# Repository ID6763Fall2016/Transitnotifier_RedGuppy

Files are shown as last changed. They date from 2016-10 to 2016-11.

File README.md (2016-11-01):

# Transitnotifier_RedGuppy
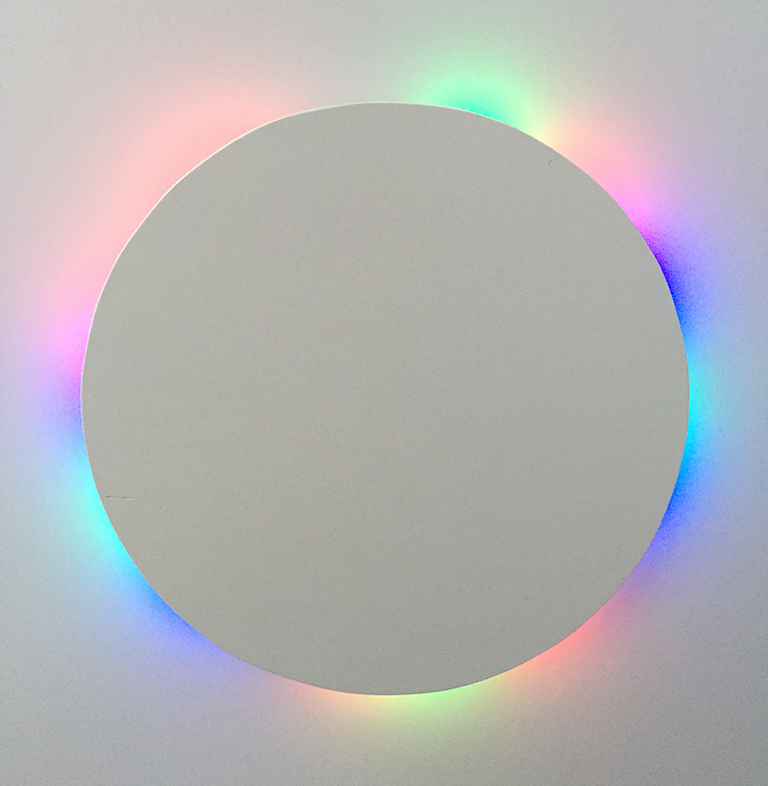
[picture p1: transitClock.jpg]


This is the transit notifier project called Buzz Clock.
You will need the following hardware and software to build the Buzz Clock: 

Hardware:
<ul>
<li>ESP8266 x 1 (adafruit Huzzah breakout for the PCB we used)</li> 
<li>NeoPixel strip x 1 (60 neoPixels.  You can use less but you'll need to modify the code heavily)</li>
<li>Battery x 1 (or a USB 5 volt power supply with power and ground connections</li>
<li>Resistor x 2 (10k and 470R)</li>
<li>Capacitor x 1 (1000U 16v or 24v) </li>
<li>Push button x 1</li>
</ul>

Software:
<ul>
<li>Adafruit NeoPixel library</li>
<li>WiFi Client Secure library</li>
<li>TinyXML library</li>
</ul>

The working code resides in the NextBusGT folder. After connecting the hardwares together and connecting ESP8266 to your laptop, you need to modify the code with your wifi SSID and Password then upload the code to the ESP8266 and it will start retrieve the data from the xml provided by http://gtbuses.herokuapp.com.

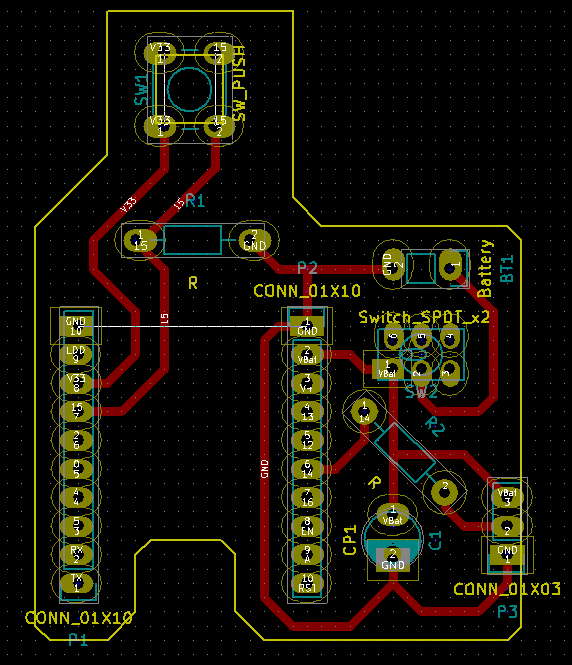
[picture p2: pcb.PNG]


If you wish to make your own PCB instead of using a breadboard for the setup you can start with our CAD files in the WiFiNeoClock director.  We used KiCad to create the board.  Additional information on working with kiCad can be found at..
http://kicad-pcb.org/

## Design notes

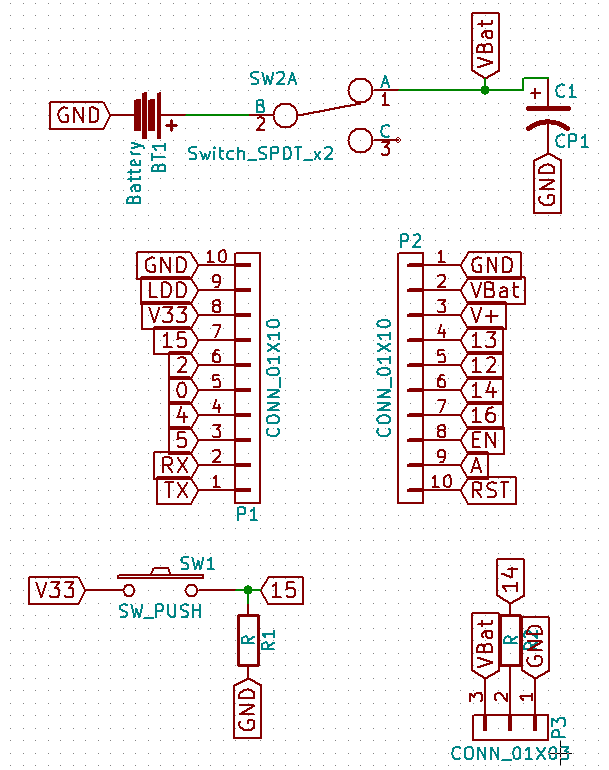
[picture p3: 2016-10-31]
schematic.PNG

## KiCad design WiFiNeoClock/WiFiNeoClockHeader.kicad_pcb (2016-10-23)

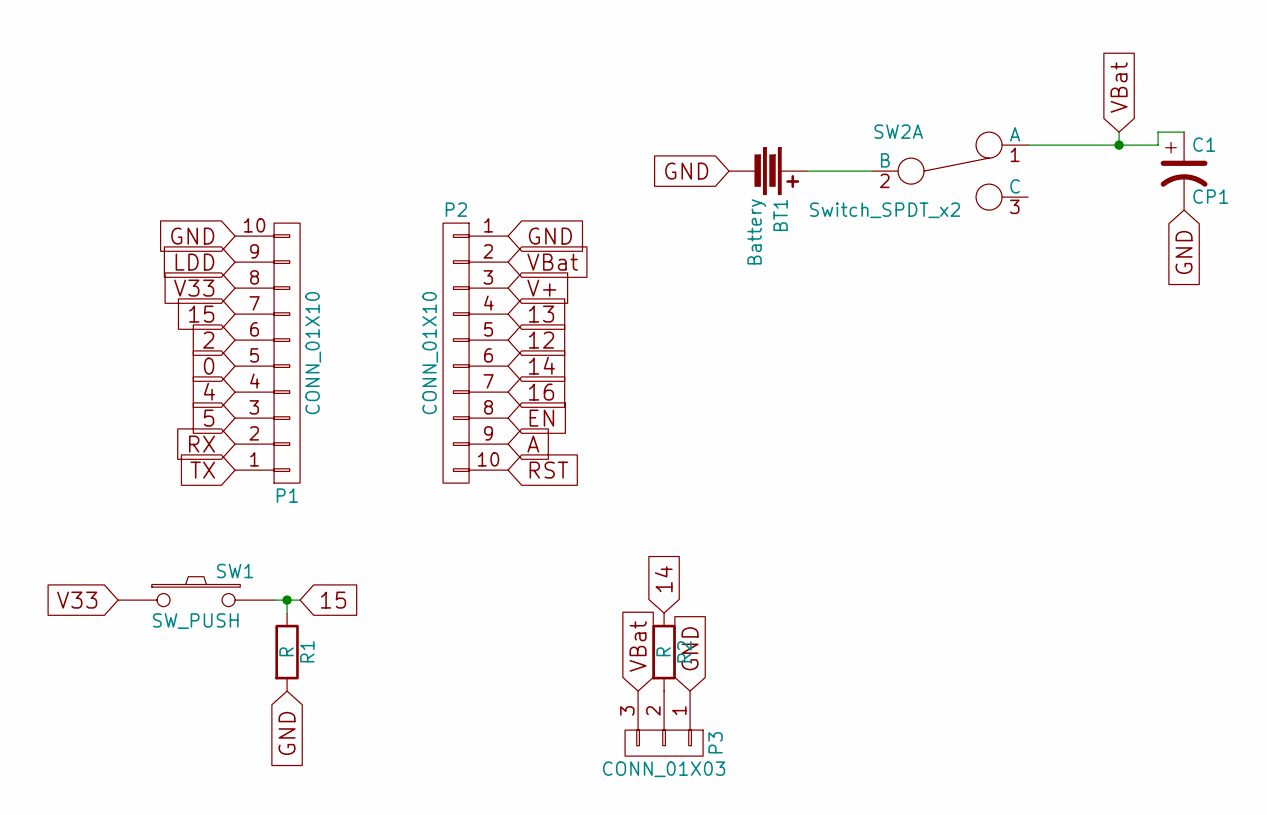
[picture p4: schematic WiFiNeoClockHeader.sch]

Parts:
BT1: Battery; Pin_Header_Straight_1x02
C1: CP1; C_Radial_D5_L11_P2.5
P1, P2: CONN_01X10; Pin_Header_Straight_1x10
P3: CONN_01X03; Pin_Header_Straight_1x03
R1, R2: R; Resistor_Horizontal_RM10mm
SW1: SW_PUSH; SW_PUSH_6mm
SW2: Switch_SPDT_x2; SW_NKK_G1xJP

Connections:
0: P1.5
2: P1.6
4: P1.4
5: P1.3
12: P2.5
13: P2.4
14: P2.6, R2.1
15: P1.7, R1.1, SW1.2
16: P2.7
A: P2.9
EN: P2.8
GND: BT1.2, C1.2, P1.10, P2.1, P3.1, R1.2
LDD: P1.9
unnamed: BT1.1, SW2.2 (B)
unnamed: P3.2, R2.2
RST: P2.10
RX: P1.2
TX: P1.1
V33: P1.8, SW1.1
V+: P2.3
VBat: C1.1, P2.2, P3.3, SW2.1 (A)

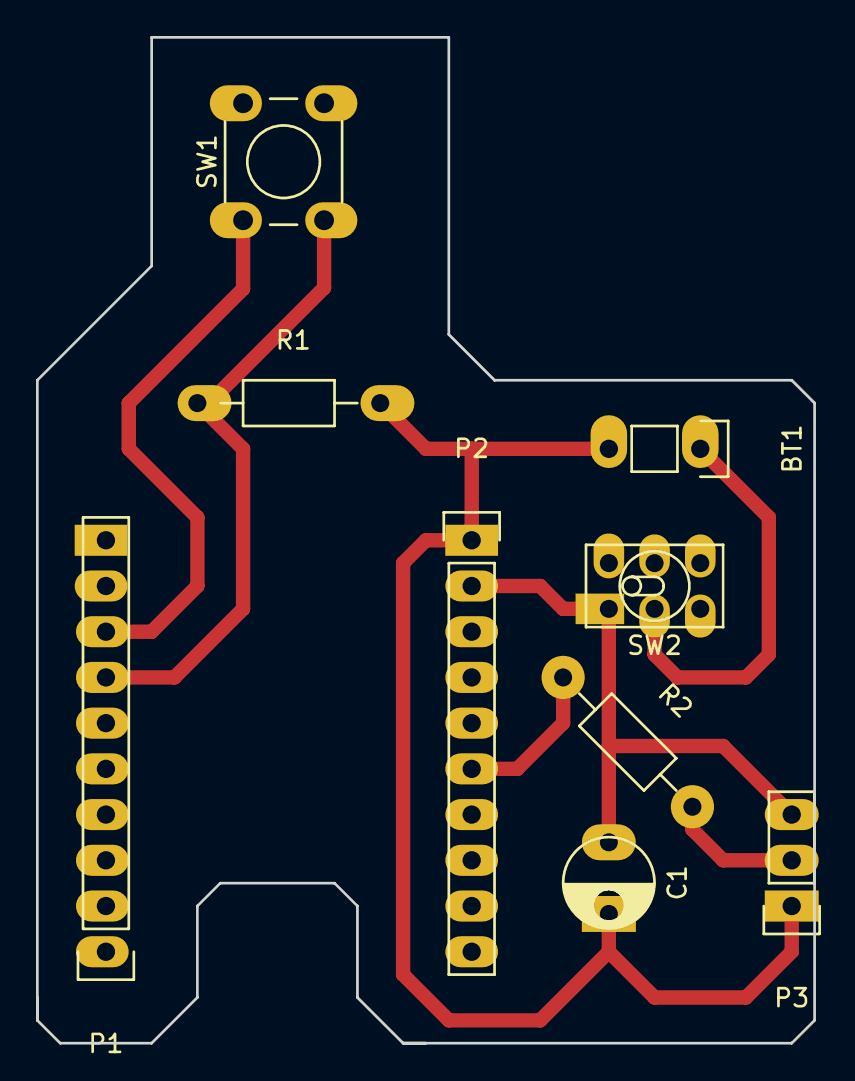
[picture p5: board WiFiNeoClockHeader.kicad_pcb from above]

Board: 2 copper layers, 43.2 x 55.9 mm, 9 parts (0 on the bottom side), 7 nets.

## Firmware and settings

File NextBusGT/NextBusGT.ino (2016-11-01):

/*
 *  HTTP over TLS (HTTPS) example sketch
 *  This program uses the Nextbus api at gtbuses.herokuapp.com to map the bus arrival times
 *  to a clock.  The idea is to present a countdown to the next bus for specific stops and show
 *  when other busses might arrive.  Each route is given a color and the next busses that are
 *  estimated to arrive within an hour are displayed.  More information can be found at...
 *  http://ipdl.gatech.edu/doie2016/projects/transit-notifier/buzz-clock-by-red-guppy/
 *  authors: colin freeman and Edith Li
 */

#include <ESP8266WiFi.h>
#include <WiFiClientSecure.h>

// we use the TinyXML library to parse the xml returned from the nextbus api
#include <TinyXML.h>

// we use Adafruit NeoPixels to display the busses on the clock and change their colors
#include <Adafruit_NeoPixel.h>

// control pin for NeoPixels is set to 14 and there are 60 neopixels, one for each second

#define PIN            14    // Node-MCU Input Pin
#define NUMPIXELS      60    // Number of Pixels on the Ring
#define BRIGHTNESS     30    // Brightness between 0 - 255

// setup placeholders for the RGB colors for each neopixel and the maximum number of routes that can be displayed at once
byte pixelColorRed, pixelColorGreen, pixelColorBlue;
byte onePixRed, onePixGreen, onePixBlue, twoPixRed, twoPixGreen, twoPixBlue, threePixRed, threePixGreen, threePixBlue;

// initialise the neopixels
Adafruit_NeoPixel pixels = Adafruit_NeoPixel(NUMPIXELS, PIN, NEO_GRB + NEO_KHZ800);

//  IMPORTANT ................................
// make sure you input your ssid and password for the wifi where the clock will be displayed
//
const char* ssid = "YOUR_WIFI_SSID_HERE";
const char* password = "YOUR_WIFI_PASSWORD_HERE";

// setup a variable to contain the site string for the api you want to use.
const char* host = "gtbuses.herokuapp.com";

// setup variables to contain the stops and routes you want to get predictions for.
// see http://gtbuses.herokuapp.com for more information on the api

const char* trolleyString = "/multiPredictions?stops=trolley|techsqua&&stops=tech|techsqua";
//const char* techString = "/multiPredictions?stops=trolley|techsqua&&stops=tech|techsqua";
//const char* blueString = "/multiPredictions?stops=blue|studcentr&&stops=red|centrstud&&stops=green|studcent";
const char* redString = "/multiPredictions?stops=blue|studcentr&&stops=red|centrstud&&stops=green|studcent";
//const char* greenString = "/multiPredictions?stops=blue|studcentr&&stops=red|centrstud&&stops=green|studcent";
const char* nightString = "/multiPredictions?stops=night|cloucomm";

// variable for the port to use
const int httpsPort = 443;

// setup a variable to contain the xml parser
TinyXML    xml;
uint8_t    buffer[150]; // For XML decoding

// creat an int to use for a delay on the server parsing call.  This is a workaround to avoid setting a long
// delay in the loop, which would slow down other functions

int serverDelay = 10;

// setup a count variable for parsing the xml into different slots in the myPredictions array
int myCount = 0;

// create an array to hold the time predictions.  We setup 15 slots 5 for each route.  This could omit the longest
// time for each route if there are more than 6 busses set to arrive for that route in less than an hour, but in testing
// this proved not to be the case.
int myPredictions[15];

// setup button pin to enable toggling between stops and routes. Sort of a mode switch
const int  buttonPin = 15; 

// Variables for counting the button clicks
int buttonPushCounter = 0;   // counter for the number of button presses
int buttonState = 0;         // current state of the button
int lastButtonState = 0;     // previous state of the button

// Setup a secure wifi client
  WiFiClientSecure client;
  
void setup() {
  // initialize the button pin as a input:
  pinMode(buttonPin, INPUT);
  
  int c;

  // setup the serial connection and init the XML parser
  Serial.begin(115200);
  Serial.println("GTBus Tracker");
  xml.init((uint8_t *)buffer, sizeof(buffer), &XML_callback);

  // connect to the wifi
  Serial.print("connecting to ");
  Serial.println(ssid);
  WiFi.begin(ssid, password);
  while (WiFi.status() != WL_CONNECTED) {
    delay(500);
    Serial.print(".");
  }
  Serial.println("");
  Serial.println("WiFi connected");
  Serial.println("IP address: ");
  Serial.println(WiFi.localIP());

  // initialize the neopixels
  pixels.begin();
  pixels.show();
  
  pixels.setBrightness(BRIGHTNESS);

  // setup the default color values for the neopixels.  This is changed later based on the routes we parse in the xml
  onePixRed = 170;
  onePixGreen = 100;
  onePixBlue = 0;
  twoPixRed = 170;
  twoPixGreen = 100;
  twoPixBlue = 0;
  threePixRed = 170;
  threePixGreen = 100;
  threePixBlue = 0;

  // parse the server one time in order to get the ball rolling.  We could wait and do this later, but this should provide some
  // information to the clock quicker.  Otherwise we have to wait for a second delay loop, which adds a few seconds.
  parseServer(serverDelay);
}

// setup a countdown variable to control the timers
uint8_t myCountdown = 0;


void loop() {
  // read the pushbutton input pin:
  buttonState = digitalRead(buttonPin);
 
  // compare the buttonState to its previous state
  if (buttonState != lastButtonState) {
    // if the state has changed, increment the counter
    if (buttonState == HIGH) {
      // if the current state is HIGH then the button
      // wend from off to on:
      if(buttonPushCounter <= 3) {
        // increment the counter
        buttonPushCounter++;
        Serial.println("on");
        Serial.print("number of button pushes:  ");
        Serial.println(buttonPushCounter);
        
        // if the button = 1 then the route and colors should be set for the trolley and the tech express at tech square
        if(buttonPushCounter == 1) {
          onePixRed = 170;
          onePixGreen = 100;
          onePixBlue = 0;
          twoPixRed = 100;
          twoPixGreen = 200;
          twoPixBlue = 0;
          threePixRed = 0;
          threePixGreen = 0;
          threePixBlue = 0;
          
          // if the route = 2 then the colors are setup for red,green, and blue routes to the student center
        }else if(buttonPushCounter == 2) {
          onePixRed = 200;
          onePixGreen = 0;
          onePixBlue = 0;
          twoPixRed = 0;
          twoPixGreen = 200;
          twoPixBlue = 0;
          threePixRed = 0;
          threePixGreen = 0;
          threePixBlue = 200;
          
          // if the route = 3 then the route is setup for night bus at clough commons
        }else if(buttonPushCounter == 3) {
          onePixRed = 170;
          onePixGreen = 0;
          onePixBlue = 170;
          twoPixRed = 170;
          twoPixGreen = 0;
          twoPixBlue = 170;
          threePixRed = 170;
          threePixGreen = 0;
          threePixBlue = 170;
          
          // if route is greater than 3 then we reset the values to the trolley at tech square.  Other routes could be added
          // here but this is enough to show how the process works
        }else if(buttonPushCounter > 3) {
          onePixRed = 170;
          onePixGreen = 100;
          onePixBlue = 0;
          twoPixRed = 100;
          twoPixGreen = 200;
          twoPixBlue = 0;
          threePixRed = 170;
          threePixGreen = 100;
          threePixBlue = 0;
          buttonPushCounter = 0;
        }
      }
      
    } else {
      // if the current state is LOW then the button
      // wend from on to off:
      Serial.println("off");
    }
    // Delay a little bit to avoid bouncing
    delay(50);
  }
  // save the current state as the last state,
  //for next time through the loop
  lastButtonState = buttonState;
  

  // get the estimates for the next bus and place them value in the myPredictions array
  parseServer(serverDelay);

  //for the number of pixels we will set a color based on the estimated time of the next bus or trolley
  for(uint8_t i=0; i<pixels.numPixels(); i++) {

       // as a default make the pixel dark
       pixelColorRed = 0;
       pixelColorBlue = 0; 
       pixelColorGreen = 0;

       // parse through the list of predictions to determine which pixels should be turned on
       for(uint8_t j=0; j<15; j++) {

          // there are 60 pixels and 60 minutes to consider in an hour so we use that as a way to parse through the pixels and times
          // we also add one minute to the estimate to give people time to get to the stop.  this is done in the 60-1 value
          if(60-myPredictions[0] < (60-1)){

            // assuming the bus isn't arriving then we set my countdown to 0 and set the color pixel values
            // we use the j value of 0-4 5-9 and 10-14 to check which predictions we are parsing so we can apply the correct
            // color to the correct pixel
            myCountdown = 0;
            if (myPredictions[j] != 0 && j<5 && i >= (60-myPredictions[j])-1 && i <= (60-myPredictions[j]) + 1) {
              pixelColorRed = onePixRed;
              pixelColorGreen = onePixGreen; 
              pixelColorBlue = onePixBlue; 
            }else if (myPredictions[j] != 0 && j>4 && j<10 && i >= (60-myPredictions[j])-1 && i <= (60-myPredictions[j]) + 1) {
              pixelColorRed = twoPixRed;
              pixelColorGreen = twoPixGreen; 
              pixelColorBlue = twoPixBlue; 
            }else if (myPredictions[j] != 0 && j>9 && j<15 && i >= (60-myPredictions[j])-1 && i <= (60-myPredictions[j]) + 1) {
              pixelColorRed = threePixRed;
              pixelColorGreen = threePixGreen; 
              pixelColorBlue = threePixBlue; 
            }

            // if a bus is arriving we start a 2 minute countdown animation that will alert people to which bus is arriving at the stop
          }else{
              if(i > myCountdown && j<5) {
                pixelColorRed = onePixRed;
                pixelColorGreen = onePixGreen; 
                pixelColorBlue = onePixBlue;
              }else if(i > myCountdown && j>4 && j<10) {
                pixelColorRed = twoPixRed;
                pixelColorGreen = twoPixGreen; 
                pixelColorBlue = twoPixBlue;
              }else if(i > myCountdown && j>9 && j<15) {
                pixelColorRed = threePixRed;
                pixelColorGreen = threePixGreen; 
                pixelColorBlue = threePixBlue;
              }else {
                pixelColorRed = 0;
                pixelColorGreen = 0; 
                pixelColorBlue = 0;
              }
              if(myCountdown > 60){
                myCountdown = 0;
              }
          }
          
      }
     
       // set the colors for all pixels on the neopixels
       pixels.setPixelColor(i, pixels.Color(pixelColorRed, pixelColorGreen, pixelColorBlue)); 
  }
    // increment the countdown
     myCountdown ++;
     pixels.show();

     // delay for 1 second.  This is mainly for the bus arriving countdown.
     delay(1000);
     
}


// function to parse the server with a small delay added to the 1 second delay in the loop.  This comes out to 10 seconds per server
// parse call
void parseServer(int myDelay){
  
  // if the delay threshold isn't met then keep delaying
  if(myCount < myDelay){
      myCount += 1;

  // else start connecting
  } else {
     Serial.print("connecting to ");
     Serial.println(host);
     if (!client.connect(host, httpsPort)) {
        Serial.println("connection failed");
        return;
     }
 

    //String url is set to the appropriate string for the current button mode
    Serial.print("requesting URL: ");
    if(buttonPushCounter <= 1 || buttonPushCounter > 3) {
      const char* url = trolleyString;
      Serial.println(url);

    // call to the server with the request
      client.print(String("GET ") + url + " HTTP/1.1\r\n" +
                  "Host: " + host + "\r\n" +
                  "User-Agent: trolleyStopClockESP8266\r\n" +
                  "Connection: close\r\n\r\n");
                 
      Serial.println("request sent");
    }else if (buttonPushCounter == 2) {
      const char* redurl = redString;
      Serial.println(redurl);
    
      client.print(String("GET ") + redurl + " HTTP/1.1\r\n" +
                  "Host: " + host + "\r\n" +
                  "User-Agent: trolleyStopClockESP8266\r\n" +
                  "Connection: close\r\n\r\n");
                 
      Serial.println("request sent");
    }else if (buttonPushCounter == 3) {
      const char* nighturl = nightString;
      Serial.println(nighturl);
    
      client.print(String("GET ") + nighturl + " HTTP/1.1\r\n" +
                  "Host: " + host + "\r\n" +
                  "User-Agent: trolleyStopClockESP8266\r\n" +
                  "Connection: close\r\n\r\n");
                 
      Serial.println("request sent");
    }

   // process the characters returned in the xml while the client is connected
   while (client.connected()) {
      if (client.available() > 0) {
        char c = client.read();
        xml.processChar(c);
       //Serial.print(c);
      }
   }
  
 
    Serial.println("==========");
    Serial.println("closing connection");
    //client.stop();
    myCount = 0;
  }
}

// placeholder variables for parsing the xml to the predictions array
int myNum = 0;
String myRoute = "";


// when xml is recieved parse it to determine the tags and the values
void XML_callback( uint8_t statusflags, char* tagName,  uint16_t tagNameLen,  char* data,  uint16_t dataLen )
{

// parsed agencyTitle to determine if we are on a new route
  if ((statusflags & STATUS_ATTR_TEXT) && !strcasecmp(tagName, "agencyTitle")) {
    myNum = 0;
  }
  // parsed routeTag to get the route information
  if ((statusflags & STATUS_ATTR_TEXT) && !strcasecmp(tagName, "routeTag")) {
    myRoute = data;
  }

// parsed the minutes tag to get actual estimates and place them within the prediction array
  if ((statusflags & STATUS_ATTR_TEXT) && !strcasecmp(tagName, "minutes")) {
        int32_t t = atoi(data); // Prediction in seconds (0 if gibberish)

        if(myRoute == "trolley"){
          myPredictions[myNum] = t;
          String myTestString = String(myPredictions[myNum]);
          Serial.println("here's stored value " + String(myNum) +" : " + myTestString);
        }else if(myRoute == "tech"){
          myPredictions[myNum+5] = t;
          String myTestString = String(myPredictions[myNum+5]);
          Serial.println("here's stored value " + String(myNum+5) +" : " + myTestString);
        }else if(myRoute == "red"){
          myPredictions[myNum] = t;
          String myTestString = String(myPredictions[myNum]);
          Serial.println("here's stored value " + String(myNum) +" : " + myTestString);
        }else if(myRoute == "green"){
          myPredictions[myNum+5] = t;
          String myTestString = String(myPredictions[myNum+5]);
          Serial.println("here's stored value " + String(myNum+5) +" : " + myTestString);
        }else if(myRoute == "blue"){
          myPredictions[myNum+10] = t;
          String myTestString = String(myPredictions[myNum+10]);
          Serial.println("here's stored value " + String(myNum+10) +" : " + myTestString);
        }else if(myRoute == "night"){
          myPredictions[myNum] = t;
          String myTestString = String(myPredictions[myNum]);
          Serial.println("here's stored value " + String(myNum) +" : " + myTestString);
        }
        
    
    }

// parsed the dirTag to determine when to increment to a new slot in the predictions array.  basically
// at the end of each prediction time
  if ((statusflags & STATUS_ATTR_TEXT) && !strcasecmp(tagName, "dirTag")) {
    myNum++;
    Serial.println(myNum);

  }
  

// the rest are other ways to parse which aren't actually used in this program
  if (statusflags & STATUS_START_TAG)
  {
    if ( tagNameLen )
    {
      //Serial.print("Start tag ");
      //Serial.println(tagName);
    }
  }
  else if  (statusflags & STATUS_END_TAG)
  {

    //Serial.print("End tag ");
    //Serial.println(tagName);
  }
  else if  (statusflags & STATUS_TAG_TEXT)
  {
    //Serial.print("Tag:");
    //Serial.print(tagName);
    //Serial.print(" text:");
    //Serial.println(data);
  }
  else if  (statusflags & STATUS_ATTR_TEXT)
  {
    //Serial.print("Attribute:");
    //Serial.print(tagName);
    //Serial.print(" text:");
    //Serial.println(data);
  }
  else if  (statusflags & STATUS_ERROR)
  {
    Serial.print("XML Parsing error  Tag:");
    Serial.print(tagName);
    Serial.print(" text:");
    Serial.println(data);
  }


}

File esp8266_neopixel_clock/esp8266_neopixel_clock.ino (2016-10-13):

#include <TimeLib.h> 
#include <ESP8266WiFi.h>
#include <WiFiUdp.h>
#include <Adafruit_NeoPixel.h>

#define PIN            14    // Node-MCU Input Pin
#define NUMPIXELS      60    // Number of Pixels on the Ring
#define BRIGHTNESS     10    // Brightness between 0 - 255

byte hourval, minuteval, secondval;
byte pixelColorRed, pixelColorGreen, pixelColorBlue;

time_t getNtpTime();
void digitalClockDisplay();
void printDigits(int digits);
void sendNTPpacket(IPAddress &address);

const char ssid[] = "CG3000DV289_xt";       //  your network SSID (name)
const char pass[] = "CG3000DV2B5C089";       // your network password

IPAddress timeServer(132, 163, 4, 101); // time-a.timefreq.bldrdoc.gov

//const int timeZone = 1;     // Central European Time
//const int timeZone = -5;  // Eastern Standard Time (USA)
const int timeZone = -4;  // Eastern Daylight Time (USA)
//const int timeZone = -8;  // Pacific Standard Time (USA)
//const int timeZone = -7;  // Pacific Daylight Time (USA)

Adafruit_NeoPixel pixels = Adafruit_NeoPixel(NUMPIXELS, PIN, NEO_GRB + NEO_KHZ800);

WiFiUDP Udp;
unsigned int localPort = 8888;  // local port to listen for UDP packets

void setup() {
  Serial.begin(115200);
  while (!Serial) ; // Needed for Leonardo only
  delay(250);
  Serial.println("TimeNTP Example");
  Serial.print("Connecting to ");
  Serial.println(ssid);
  WiFi.begin(ssid, pass);
  
  while (WiFi.status() != WL_CONNECTED) {
    delay(500);
    Serial.print(".");
  }
  pixels.begin();
  pixels.show();
  
  pixels.setBrightness(BRIGHTNESS);
  delay(500);
  
  Serial.print("IP number assigned by DHCP is ");
  Serial.println(WiFi.localIP());
  Serial.println("Starting UDP");
  Udp.begin(localPort);
  Serial.print("Local port: ");
  Serial.println(Udp.localPort());
  Serial.println("waiting for sync");
  setSyncProvider(getNtpTime);
}

time_t prevDisplay = 0; // when the digital clock was displayed

void loop() {  
  if (timeStatus() != timeNotSet) {
    if (now() != prevDisplay) { //update the display only if time has changed
      prevDisplay = now();
      digitalClockDisplay(); 
      secondval = second();
      minuteval = minute();
      hourval = hour();

      if(hourval > 12) hourval -= 12; // This clock is 12 hour, if 13-23, convert to 0-11
     
      //hourval = (hourval*60 + minuteval) / 30;  
      //minuteval = minuteval / 2.5;
      hourval = (60/12)* hourval;
      Serial.println(hourval);  
      minuteval = minuteval;
      //secondval = secondval /2.5;
      secondval = secondval;
      
      for(uint8_t i=0; i<pixels.numPixels(); i++) {
     
      if (i >= minuteval-1 && i <= minuteval+1) {
        pixelColorRed = 150;  
      }
      else {
        pixelColorRed = 0;
      }
     
      if (i <= hourval && i != minuteval-1 && i != minuteval+1 && i != minuteval) {
        pixelColorGreen = 150;   
      }
      else {
        pixelColorGreen = 0;
      }
      if (i == secondval) {
        pixelColorBlue = 150;
      }
      else {
        pixelColorBlue = 0;
      }
     
      pixels.setPixelColor(i, pixels.Color(pixelColorRed, pixelColorGreen, pixelColorBlue));
      }
    }
  }
  pixels.show();
  delay(100);
}

void colorWipe(uint32_t c, uint8_t wait) {
      for(uint16_t i=0; i<pixels.numPixels(); i++) {
      pixels.setPixelColor(i, c);
      pixels.show();
      delay(wait);
      }
    }

void digitalClockDisplay(){
  // digital clock display of the time
  Serial.print(hour());
  printDigits(minute());
  printDigits(second());
  Serial.print(" ");
  Serial.print(day());
  Serial.print(".");
  Serial.print(month());
  Serial.print(".");
  Serial.print(year()); 
  Serial.println(); 
}

void printDigits(int digits){
  // utility for digital clock display: prints preceding colon and leading 0
  Serial.print(":");
  if(digits < 10)
    Serial.print('0');
  Serial.print(digits);
}

/*-------- NTP code ----------*/

const int NTP_PACKET_SIZE = 48; // NTP time is in the first 48 bytes of message
byte packetBuffer[NTP_PACKET_SIZE]; //buffer to hold incoming & outgoing packets

time_t getNtpTime()
{
  while (Udp.parsePacket() > 0) ; // discard any previously received packets
  Serial.println("Transmit NTP Request");
  sendNTPpacket(timeServer);
  uint32_t beginWait = millis();
  while (millis() - beginWait < 1500) {
    int size = Udp.parsePacket();
    if (size >= NTP_PACKET_SIZE) {
      Serial.println("Receive NTP Response");
      Udp.read(packetBuffer, NTP_PACKET_SIZE);  // read packet into the buffer
      unsigned long secsSince1900;
      // convert four bytes starting at location 40 to a long integer
      secsSince1900 =  (unsigned long)packetBuffer[40] << 24;
      secsSince1900 |= (unsigned long)packetBuffer[41] << 16;
      secsSince1900 |= (unsigned long)packetBuffer[42] << 8;
      secsSince1900 |= (unsigned long)packetBuffer[43];
      return secsSince1900 - 2208988800UL + timeZone * SECS_PER_HOUR;
    }
  }
  Serial.println("No NTP Response :-(");
  return 0; // return 0 if unable to get the time
}

// send an NTP request to the time server at the given address
void sendNTPpacket(IPAddress &address)
{
  // set all bytes in the buffer to 0
  memset(packetBuffer, 0, NTP_PACKET_SIZE);
  // Initialize values needed to form NTP request
  // (see URL above for details on the packets)
  packetBuffer[0] = 0b11100011;   // LI, Version, Mode
  packetBuffer[1] = 0;     // Stratum, or type of clock
  packetBuffer[2] = 6;     // Polling Interval
  packetBuffer[3] = 0xEC;  // Peer Clock Precision
  // 8 bytes of zero for Root Delay & Root Dispersion
  packetBuffer[12]  = 49;
  packetBuffer[13]  = 0x4E;
  packetBuffer[14]  = 49;
  packetBuffer[15]  = 52;
  // all NTP fields have been given values, now
  // you can send a packet requesting a timestamp:                 
  Udp.beginPacket(address, 123); //NTP requests are to port 123
  Udp.write(packetBuffer, NTP_PACKET_SIZE);
  Udp.endPacket();
}

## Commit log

2016-10-17 "add pcb"
    [WiFiNeoClock.kicad_pcb, WiFiNeoClock.sch]
2016-10-18 add new pcb for neoclock
    [WiFiNeoClockHeader.kicad_pcb, WiFiNeoClockHeader.sch]
2016-10-21 updated pcb to fix milling errors
    spread out the traces and fixed the drill holes for the Capacitor
    [WiFiNeoClockHeader.kicad_pcb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]
2016-10-23 updated kicad files with thicker traces and pads to help with soldering
    [WiFiNeoClockHeader.kicad_pcb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]
2016-10-25 Added hooks for button pushes to swap routes
    [NextBusGT.ino]
2016-11-01 added latest cad files for the wifi clock board
    [WiFiNeoClock.kicad_pcb, WiFiNeoClock.sch, WiFiNeoClockHeader.kicad_pcb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]
2016-11-01 added image of pcb to readme
